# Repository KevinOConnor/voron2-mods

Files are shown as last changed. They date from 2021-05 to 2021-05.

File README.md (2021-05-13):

This repository documents modifications to my Voron2.4 250mm printer
(serial number V2.1114).

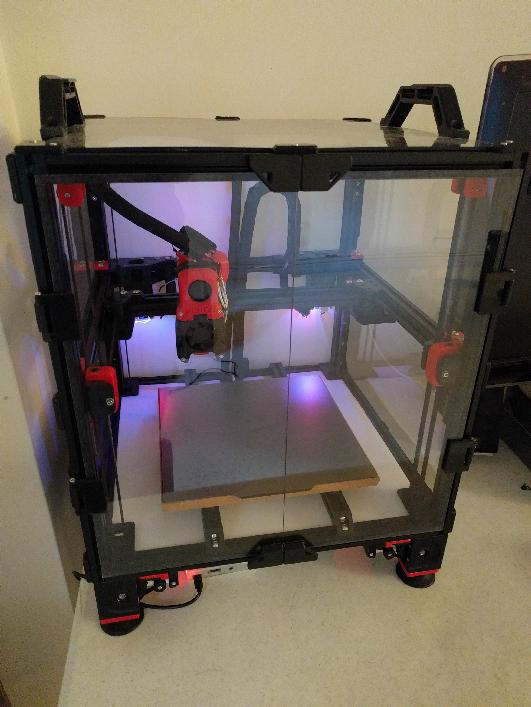
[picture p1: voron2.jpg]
voron2


Assembly of the printer started in January of 2021.  The mechanics of
the printer mainly follow the standard Voron2.4 build at that time.

# Electronics

The printer uses a custom electronics setup using Huvud boards,
sensorless homing, and Klipper "multi-mcu" homing.  See the
[electronics document](electronics/electronics.md) for details.

# Bed

The printer bed heater is controlled by a separate thermistor on the
aluminum heat spreader and it uses cork board for insulation.  See the
[bed document](bed/bed.md) for details.

# Panels

Several minor changes were made to the exterior enclosure.  Details
are available in the [panels document](panels/panels.md).

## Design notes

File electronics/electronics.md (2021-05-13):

This document describes a custom electronics setup for a Voron2.4
printer.

# Huvud boards

The printer uses three [Huvud
boards](https://github.com/bondus/KlipperToolboard).  One is mounted
to the toolhead stepper motor and the other two are mounted to the
back of the corexy stepper motors.

A single CAN bus is used to communicate with these Huvud boards.  The
Raspberry Pi running Klipper has a [canable](https://canable.io/) USB
adapter for CAN bus communication.

A custom wiring harness was made for the CAN bus - the bus routes the
toolhead huvud board, to the canable usb adapter, to the rear-right
corexy huvud board, and finally to the rear-left corexy huvud board.
The wiring harness is comprised of four 20AWG wires: 24V, GND, CANH,
CANL.  A 120 Ohm "through hole" resistor is soldered between the CAN
wires at both ends of the wiring bus (near the toolhead Huvud board
and near the rear-left corexy Huvud board).

The toolhead wires follow the filament "reverse bowden" tube.  The
standard Voron XY cable chains are not deployed.  I purchased "1/2
inch black PET wire loom split tubing" (from Amazon) for wire
management.

For the wires between the two corexy stepper motors, I designed a
[rear wire clip](rear_wire_guide.stl) to route the wires along the
2020 aluminum extrusion.

# Homing

This printer uses an experimental Klipper setup using multi-mcu
homing.  The corexy and Z stepper motors also use "sensorless homing"
via Trinamic tmc2209 drivers.  The standard Voron XY endstop switches
were not deployed.  The standard Voron Z endstop switch was not
deployed.

The Z sensorless homing is done by moving the Z away from the bed
until each Z carriage contacts the top of the rail.  I designed [Z
rail ends](z_stop.stl) for the top of rail contact point.

# Other

The Z stepper motors are controlled by a "bigtreetech mini-mz" board.
This board was deployed because of its availability at the time of
assembly.  The board is mounted under the printer via the DIN rails.
(The screw holes on the standard Voron Raspberry Pi holder was close
enough to the mini-mz mounting holes that I could reuse that holder to
mount this board.)

A chamber thermistor is deployed on the rear-left corexy Huvud board.
It is a generic "NTC 3950" glass bead type thermistor (purchased from
Amazon as a ten pack).

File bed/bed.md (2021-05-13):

This document describes modifications to a Voron2.4 heated bed.

The printer has a standard 250mm aluminum heat spreader and 200mm
Keenovo heater (purchased as a kit from DigMach).  On top of the
aluminum heat spreader is a magnetic sheet and PEI covered spring
steel sheet (purchased from Energetic).

# Thermistor on aluminum heat spreader

The standard thermistor on the back of the Keenovo heater does not
provide an accurate estimate of the bed surface temperature.  I
deployed a separate thermistor attached directly to the aluminum heat
spreader to improve temperature estimates.

I used a generic "NTC 3950" glass bead type thermistor (purchased from
Amazon as a ten pack).  To mount it to the bed I started with a common
"22-16AWG ring wire connector":

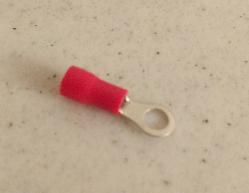
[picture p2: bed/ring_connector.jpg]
ring_connector


I then used two pairs of pliers to remove the red plastic sheathing
from the connector.  This left just the metal part of the ring
connector.  The glass bead on the thermistor was small enough to pass
through the wire tube on the connector.  Using a standard crimping
tool, I slightly crimped the part of the wire tube nearest the ring,
such that the glass bead could enter the wire tube but not pass all
the way through it.  With the glass bead inside the tube I then
carefully crimped the wire tube furthest from the ring, such that the
glass bead was trapped inside the tube.  I then carefully crimped
either side of the tube so as to remove any movement of the glass bead
within the tube.  It is relatively easy to break the glass bead on the
thermistor - it is a good idea to buy extra thermistors if attempting
the above procedure.

Finally, I used an M3 screw to mount the resulting "ring connector
with thermistor" to the underside of the aluminum heat spreader.

# Insulated bed

I used cork board to insulate the bed.  I did this for three reasons:
to better promote a consistent bed surface temperature at the edges
and corners of the bed, to improve the bed surface temperature
estimate from the thermistor mounted under the bed, and to improve the
bed aesthetic.

I used "2mm thick cork sheets with self-adhesive" (purchased from
Amazon). I started by cutting sections of a cork sheet so that they
fit around the bed heater and other components on the bottom of the
aluminum heat spreader:

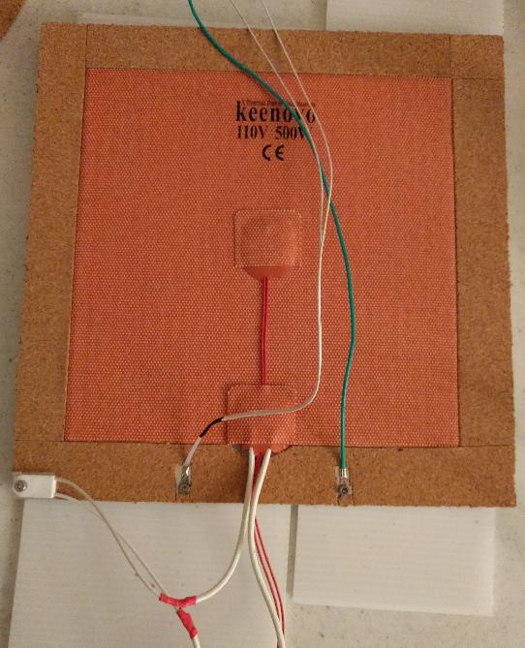
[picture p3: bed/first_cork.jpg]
first_cork


From left to right, the components at the bottom of the above picture
are: the bed fuse (115 degrees Celsius), the "NTC 3950 thermistor on
ring connector", the Keenovo wires, and the ground wire.

The second layer of cork board was then applied on top of the first
layer:

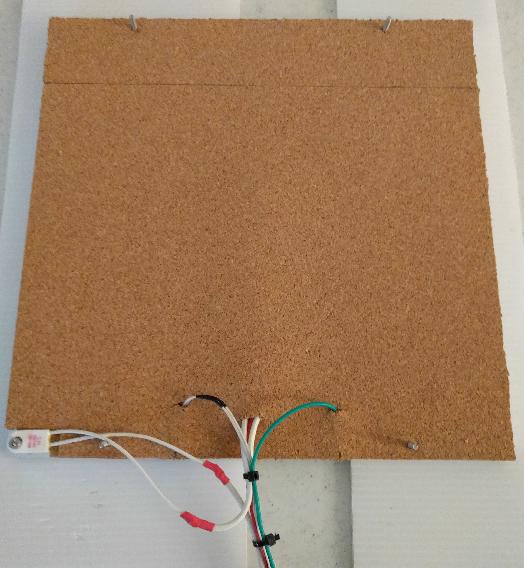
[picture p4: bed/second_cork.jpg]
second_cork


The cork sheets that I purchased were not large enough to fully cover
the bed with a single sheet.  So, I used multiple sheets to cover the
full space.

I intentionally routed the ground and thermistor wires towards the
center of the bed for better heat insulation at the sides and so that
those wires would not pull down on the cork board.

Finally, I cut strips of cork board and attached them to the sides of
the bed:

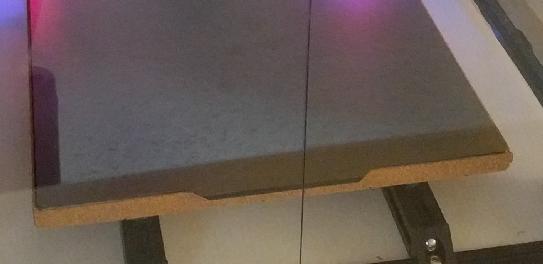
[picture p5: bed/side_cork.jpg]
side_cork


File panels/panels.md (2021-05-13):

This document describes some minor customizations of a Voron2.4
enclosure.

# No exhaust fan

I did not deploy the standard Voron exhaust filter / fan.  The rear
coroplast panel only has a small hole for the "reverse bowden" ptfe
tube.

I designed a [tube guide](tube_guide.stl) to support the filament
tube.  It is mounted near the center of the rear top horizontal
aluminum extrusion.

# Separate filament spool holder

I did not deploy the standard Voron spool holder.  I use a separate
[spool holder in a ziplock
bag](https://github.com/KevinOConnor/zipspool).

# Polycarbonate panels

I ordered polycarbonate panels (from TAP Plastics) instead of the
standard acrylic panels.

The panels were slightly larger than requested.  This caused an issue
with the standard Voron hinges.  I designed a custom door hinge
([hinge for frame](hinge_frame.stl) and [hinge for
door](hinge_door.stl)) so that I could mount the slightly over-sized
front door panels.

# Other

The Misumi "blind corner joints" have screw holes in the vertical
extrusions.  These screw holes provide a hole into the internal
chamber.  I designed simple plastic [plugs](screw-plug.stl) to fill
these holes (both to reduce air flow through the hole and for improved
aesthetic).

I deployed [Voron2.2
handles](https://github.com/VoronDesign/Voron-2/blob/Voron2.2/STLs/VORON2.2/Panel_Mounting/Handles_Panel_Rests_Misc/handle_3mm_x2_Rev1.stl)
to make it easier to move the printer.

The standard Voron deck panel calls for a hole to route the bed wires
through.  I did not make this hole in the coroplast.  Instead, I route
all wires (toolhead, corexy, and bed) through a single hole at the
rear of the deck panel.

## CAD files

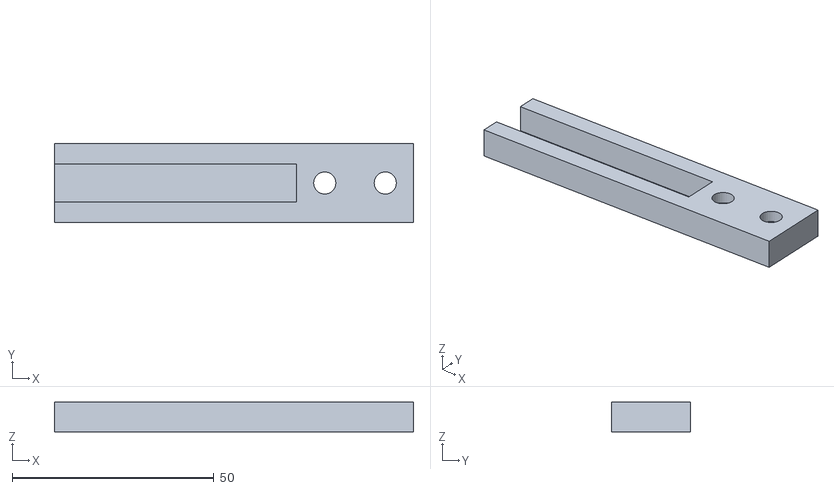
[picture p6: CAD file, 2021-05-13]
electronics/z_stop.stl
89.0 x 19.5 x 7.40

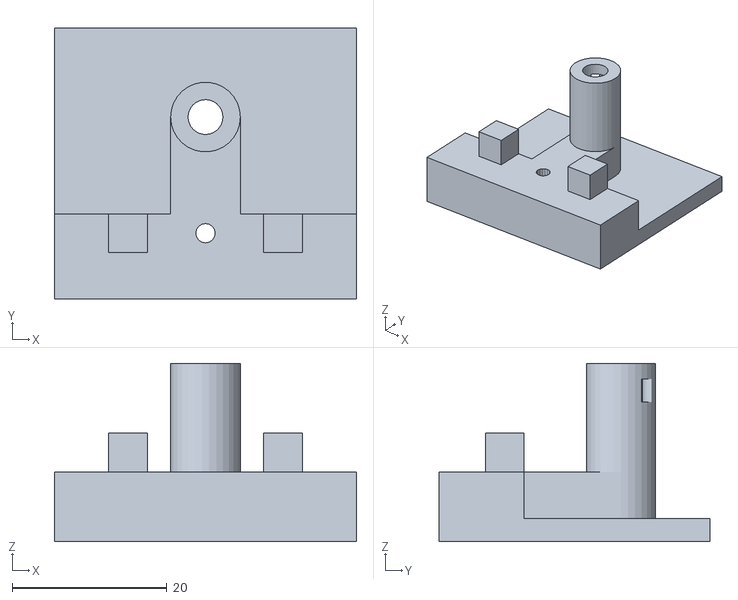
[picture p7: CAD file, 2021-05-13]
panels/tube_guide.stl
39.0 x 35.0 x 23.0

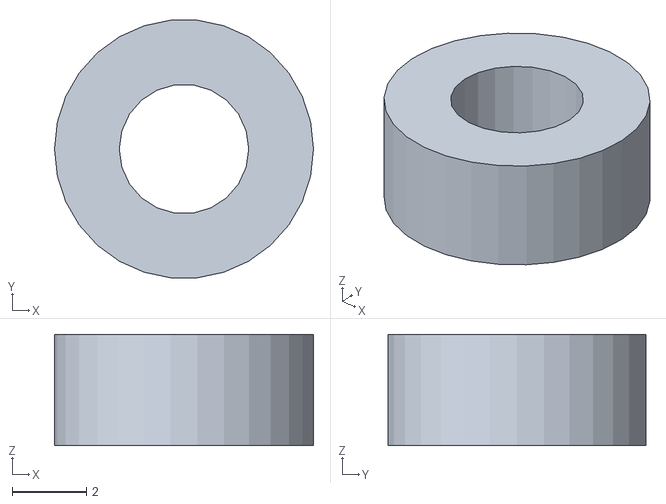
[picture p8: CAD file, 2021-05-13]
electronics/stepper_spacer.stl
7.00 x 6.96 x 3.00

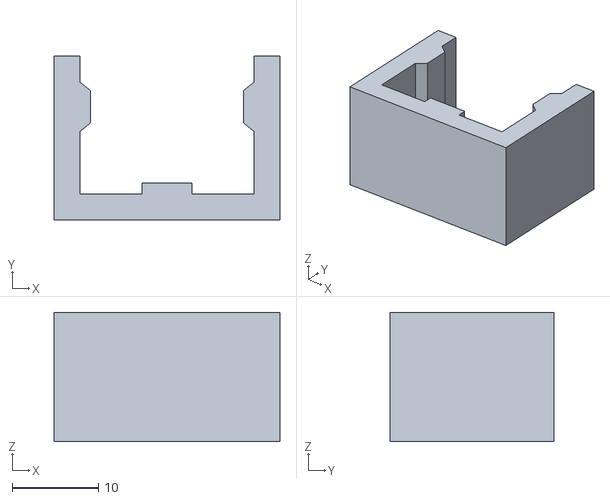
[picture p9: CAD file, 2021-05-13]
electronics/rear_wire_guide.stl
26.2 x 19.0 x 15.0

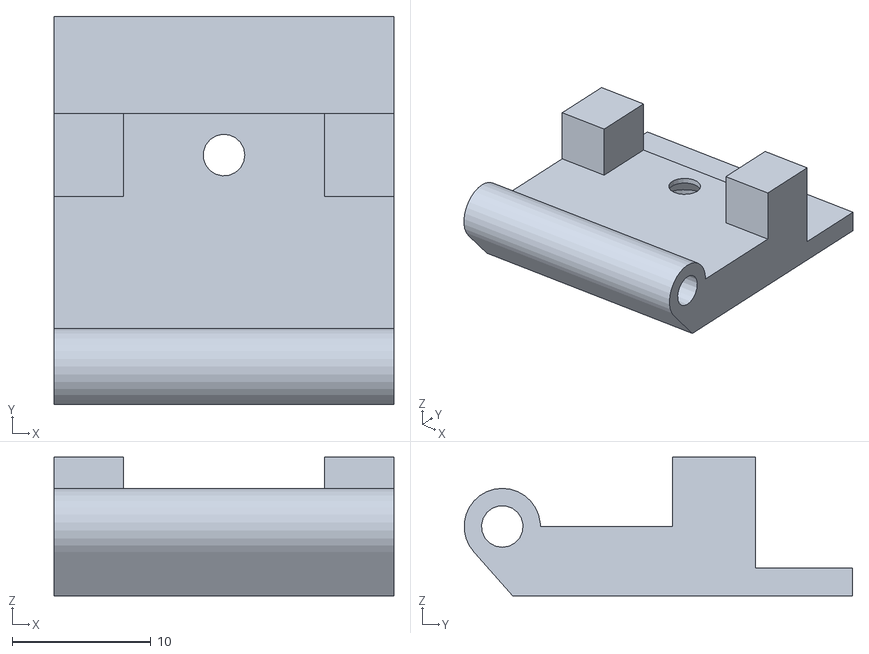
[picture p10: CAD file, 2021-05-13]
panels/hinge_frame.stl
24.5 x 28.0 x 10.0

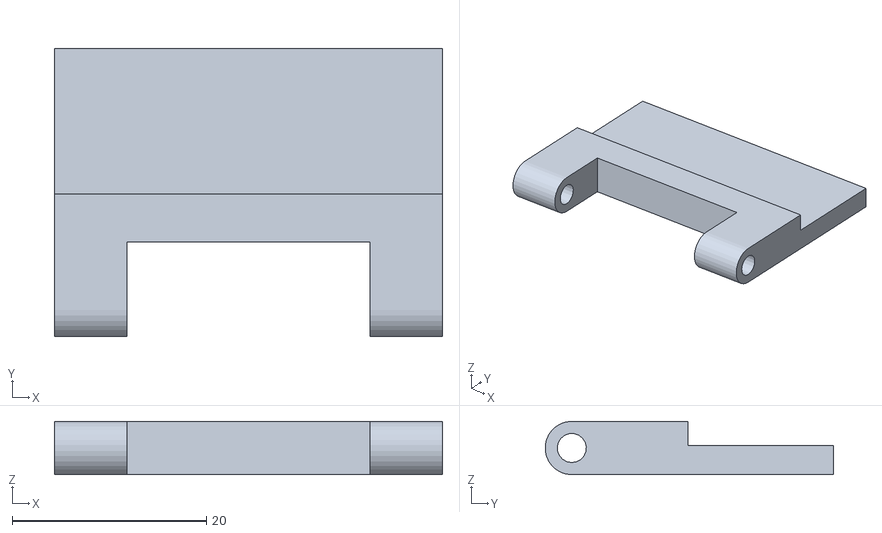
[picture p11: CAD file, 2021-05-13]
panels/hinge_door.stl
40.0 x 29.7 x 5.50

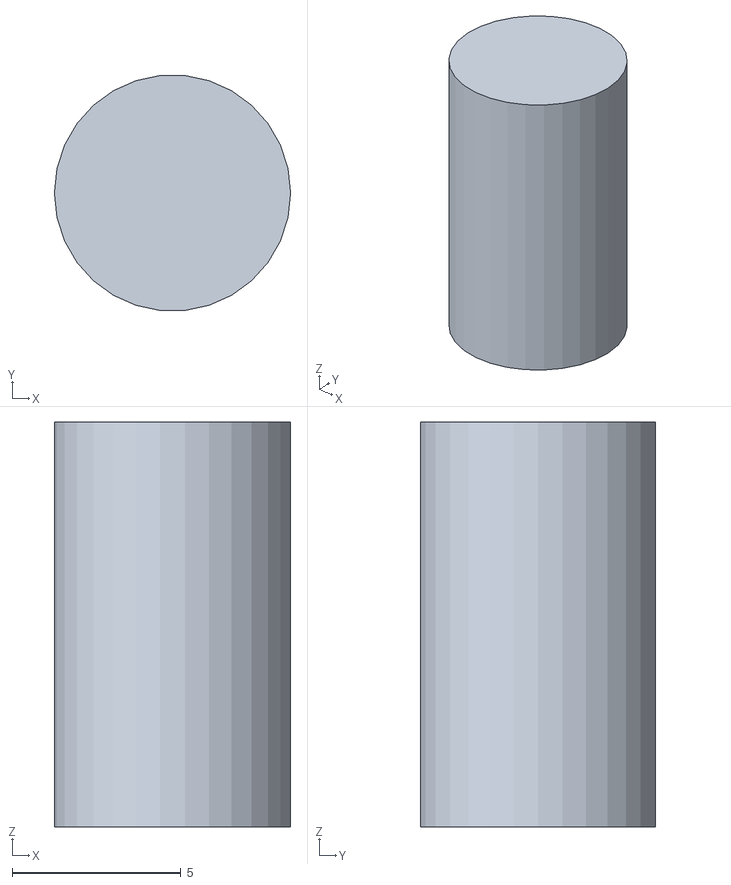
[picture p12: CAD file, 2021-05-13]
panels/screw-plug.stl
7.00 x 6.96 x 12.0

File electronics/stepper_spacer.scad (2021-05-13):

// Simple stepper motor screw spacers for huvud board
//
// Copyright (C) 2021  Kevin O'Connor <kevin@koconnor.net>
//
// This file may be distributed under the terms of the GNU GPLv3 license.

screw_dia = 3.5;
spacer_dia = 7;
CUT = 0.01;
$fs = 0.5;

module stepper_spacer(height) {
    difference() {
        cylinder(d=spacer_dia, h=height);
        translate([0, 0, -CUT])
        cylinder(d=screw_dia, h=height + 2*CUT);
    }
}

//
// Object selection
//

stepper_spacer(3);

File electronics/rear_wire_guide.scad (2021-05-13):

// Clip to hold wires inside a 2020 extrusion
//
// Copyright (C) 2021  Kevin O'Connor <kevin@koconnor.net>
//
// This file may be distributed under the terms of the GNU GPLv3 license.

height = 15;
thick = 3;
slack = .250;
rail_length = 20 + slack;
rail_insert_length = 6 - slack;
CUT=.01;
$fs = 0.5;

module wire_guide() {
    rail_beam_length = (rail_length - rail_insert_length)/2;
    width = rail_beam_length + rail_insert_length + 2*thick;

    module base_guide() {
        difference() {
            cube([rail_length + 2*thick, width, height]);
            translate([thick, thick, -CUT])
                cube([rail_length, width-thick+CUT, height+2*CUT]);
        }
    }
    clip_inset = 1.25;
    module clip() {
        slope_length = 1;
        hull() {
            cube([CUT, rail_insert_length, height]);
            translate([clip_inset, slope_length, 0])
                cube([CUT, rail_insert_length - 2*slope_length, height]);
        }
    }

    base_guide();
    translate([rail_beam_length + thick, thick-CUT, 0])
        cube([rail_insert_length, clip_inset+CUT, height]);
    translate([thick-CUT, rail_beam_length + thick, 0])
        clip();
    translate([rail_length + thick + CUT, rail_beam_length + thick, 0])
        mirror([1, 0, 0])
            clip();
}

wire_guide();

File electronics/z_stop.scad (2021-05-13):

// Max Z stop for Voron 2.4 printers
//
// Copyright (C) 2021  Kevin O'Connor <kevin@koconnor.net>
//
// This file may be distributed under the terms of the GNU GPLv3 license.

// extrusion width = 20mm ; rail width = 9mm, rail depth = 6.5mm
// spring nut length = 13mm ; voron xy parts above carriage = 60mm
// m5 nut dia = 4.9mm ; m5 button head dia = 9.25

block_width = 19.5;
block_depth = 7.4;
railcut_length = 60;
block_length = railcut_length + 7 + 15 + 5 + 2;
railcut_width = 9.5;
railcut_depth = 6.8;
screw_dia = 5.5;
screw_head_dia = 10;
CUT = 0.01;
$fs = 0.5;

//
// Z stop
//

module z_stop() {
    module screwcut(x) {
        translate([x, 0, -CUT])
            cylinder(d=screw_dia, h=block_depth+2*CUT);
        bury = 3;
        translate([x, 0, -CUT])
            cylinder(d=screw_head_dia, h=bury+CUT);
        translate([x, 0, bury-CUT])
            cylinder(d1=screw_head_dia, d2=screw_dia, h=1.5+CUT);
    }
    module block() {
        difference() {
            translate([0, -block_width/2, 0])
                cube([block_length, block_width, block_depth]);
            translate([-CUT, -railcut_width/2, block_depth-railcut_depth])
                cube([railcut_length+CUT, railcut_width, railcut_depth+CUT]);
            screw1_x = railcut_length + screw_head_dia/2 + 2;
            screw2_x = screw1_x + 15;
            screwcut(screw1_x);
            screwcut(screw2_x);
        }
    }
    block();
}

//
// Object selection
//

z_stop();

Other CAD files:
panels/hinge.scad
panels/screw-plug.scad
panels/tube_guide.scad
